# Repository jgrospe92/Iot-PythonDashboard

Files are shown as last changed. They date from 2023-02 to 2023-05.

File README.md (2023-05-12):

# Iot-PythonDashboard
Academic Project for IoT Course.

# Project Description
By utilizing sensors, actuators, motors, Single-board computers, and micro-controllers, students
design and simulate a smart home. They capture environmental information and make a decision
based on received data. They also develop access control and occupancy systems and transfer all
data to the cloud or a local server. Finally, they design and develop a web-based IoT dashboard to
control and monitor the system.

# IOT dashboard Gadgets
## LED Controll
LED_control
## LED switch Sensor
Untitled video - Made with Clipchamp

## Temperature Controll
fan_control

# Virtual Environment
## Windows
- cd to the to main directory
- Once inside Iot-PythonDashboard
- Run the command `Scripts\activate` to activate the virtual environment
- Your terminal should change into this (Iot-PythonDashboard)
- To deactivate it, run the command `deactivate`

## Arduino & MAc
- cd to the to main directory
- Once inside Iot-PythonDashboard
- Run the command `source Scripts/activate` to activate the virtual environment
- Your terminal should change into this (Iot-PythonDashboard)
- To deactivate it, run the command `deactivate`
# Important
- Make sure you name the folder Iot-PythonDashboard
- if you don't have the virtual environment installed, you can't activate the virtual environment
- run this command to install it `pip install virtualenv`

# Installing Dependencies
- Make sure you're in the python environment
- Then run the command `pip install -r requirements.txt`
- If the above command doesnt work
- You have to install each dependencies manually by running this command
- `pip install {the name of the dependency}`
- Check the requirements.txt for the names

# How to install SqLite Browser
- NOTE: You don't have to be in virtual environment to install it
- Run this command `sudo apt-get install sqlitebrowser`
- Once installed, check the raspberry icon under programming

# How to run the project
- Look for the app.py and execute it
- It should provide you a localhost address

# Email Libraries
- Red mail
  - For sending email 
  - [Documentation](https://red-mail.readthedocs.io/en/stable/tutorials/getting_started.html)
- Redbox
  - For receiving email
  - [Documentation](https://red-box.readthedocs.io/en/latest/tutorials/getting_started.html)
- :warning: IMPORTANT In order for the email function to work, you have to create email_config.py in src/Controller/
- Inside that python file add you credentials as key value pair
- example : `username = "your usename` `password = "your password"`

# MQTT Broker
- [Paho Broker](https://pypi.org/project/paho-mqtt/)
- NOTE: You must create `broker_IP.py` in src/Controller/
- Inside the python file create a variable `ipaddress = 'BROKER IP ADDRESS'`
- Replace `BROKER IP ADDRESS` with the right MQTT Broker IP address 

# wifi username and password
- In order to hide your wifi confidentials we will need to create a header file
- In the Arudino IDE click the down arrow button on the top right side of the window
- Click New Tab then name it to `arduino_secrets.h`
- then define two variables
- `#define SECRET_SSID "Your network SSID"`
- `#define SECRET_PASS "Your network password"`
- `#define SECRET_IP "Your network IP"`

# How to run the server in LAN
- set `app.run_server(host='0.0.0.0', port=1234)`
- Now we need network ip address, in ther terminal, run `ifconfig`
- you should see wlan0: ... inet x.y.z
- On the another computer, open any browser and type in the url
- the network ip address : port number
- ex. 10.0.1.2:1234
# Can't connect
- if you get an error that says, 'connection refuse'
- try using another port

# Plottly Dash Documentation
- https://dash.plotly.com/

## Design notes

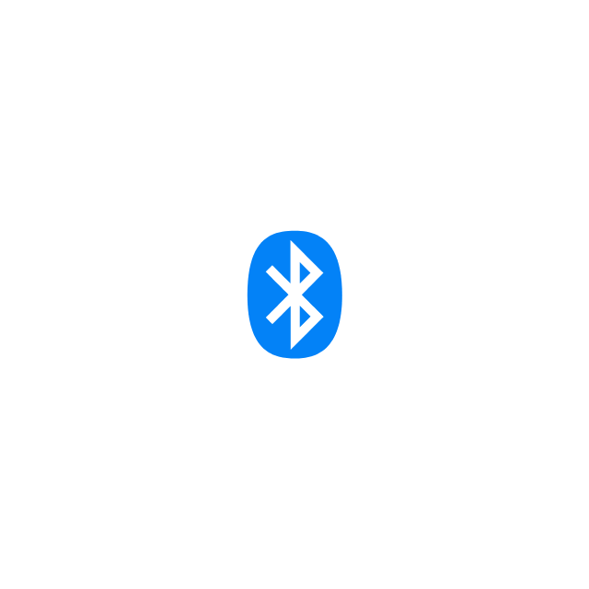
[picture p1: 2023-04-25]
assets/images/bluetooth.gif

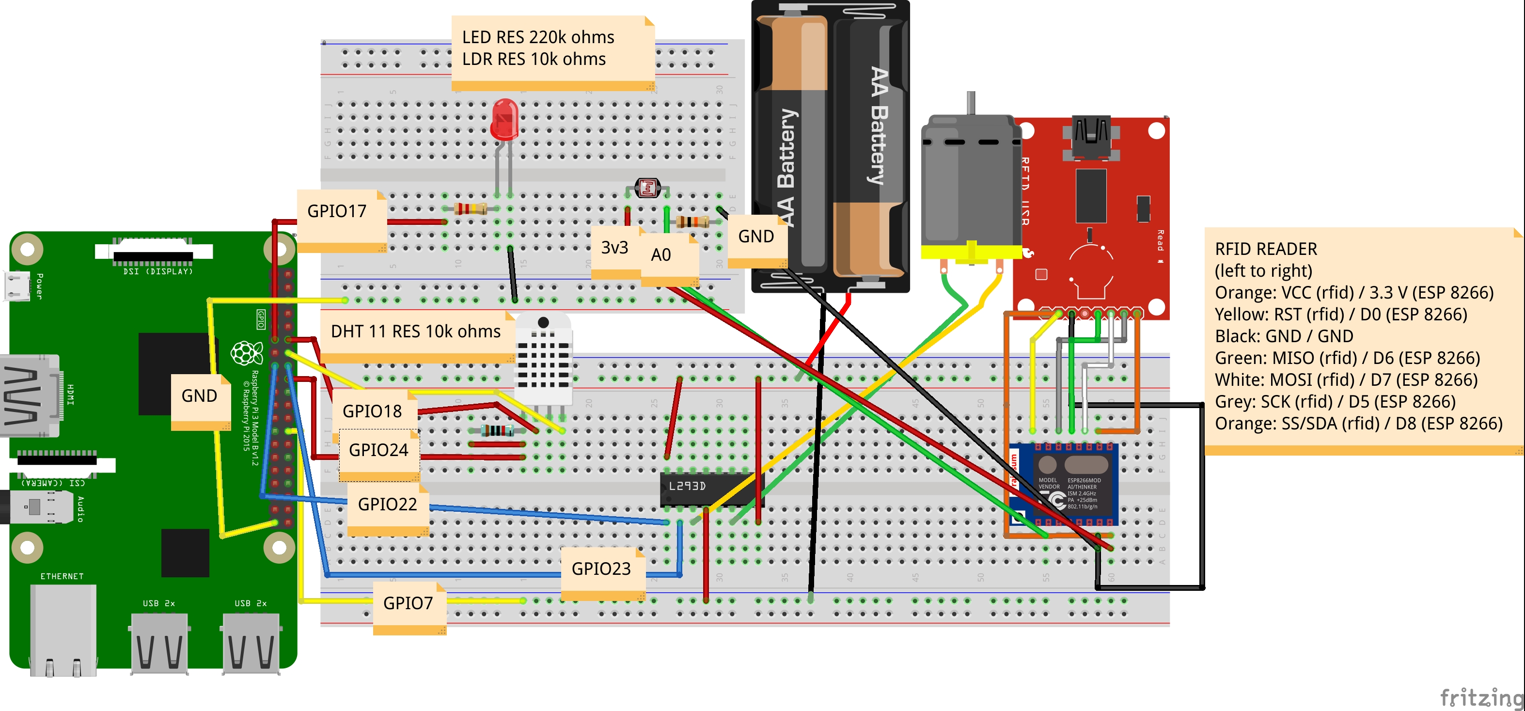
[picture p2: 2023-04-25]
Fritzing Phases/FinalFritzing_bb.jpg

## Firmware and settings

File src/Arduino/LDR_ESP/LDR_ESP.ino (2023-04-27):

#include <ESP8266WiFi.h>
#include <PubSubClient.h>
#include "arduino_secrets.h"


// RFID
#include <SPI.h>
#include <MFRC522.h>
#define SS_PIN D8
#define RST_PIN D0
MFRC522 rfid(SS_PIN, RST_PIN); // Instance of the class
MFRC522::MIFARE_Key key;
// Init array that will store new NUID
byte nuidPICC[4];
String card_id = "";


//const char* ssid = "TP-Link_2AD8";
const char* ssid = SECRET_SSID;
const char* password = SECRET_PASS;
const char* mqtt_server = SECRET_IP;
WiFiClient vanieriot;
PubSubClient client(vanieriot);
void setup_wifi() {
 delay(10);
 // We start by connecting to a WiFi network
 Serial.println();
 Serial.print("Connecting to ");
 Serial.println(ssid);
 WiFi.begin(ssid, password);
 while (WiFi.status() != WL_CONNECTED) {
 delay(500);
 Serial.print(".");
 }
 Serial.println("");
 Serial.print("WiFi connected - ESP-8266 IP address: ");
 Serial.println(WiFi.localIP());
}
void callback(String topic, byte* message, unsigned int length) {
 Serial.print("Message arrived on topic: ");
 Serial.print(topic);
 Serial.print(". Message: ");
 String messagein;

 for (int i = 0; i < length; i++) {
 Serial.print((char)message[i]);
 messagein += (char)message[i];
 }

}
void reconnect() {
 while (!client.connected()) {
 Serial.print("Attempting MQTT connection...");
 if (client.connect("vanieriot")) {
 Serial.println("connected");

 } else {
 Serial.print("failed, rc=");
 Serial.print(client.state());
 Serial.println(" try again in 3 seconds");
 // Wait 5 seconds before retrying
 delay(3000);
 }
 }
}
void setup() {

 Serial.begin(115200);
 setup_wifi();
 client.setServer(mqtt_server, 1883);
 client.setCallback(callback);
 // setup for the rfid
 SPI.begin(); // Init SPI bus
 rfid.PCD_Init(); // Init MFRC522
 Serial.println();
 Serial.print(F("Reader :"));
 rfid.PCD_DumpVersionToSerial();
 for (byte i = 0; i < 6; i++) {
  key.keyByte[i] = 0xFF;
 }
 //Note: To use the RFID RC522 module we use the SPI.h library which will allow us to
 //establish the communication between the ESP8266 card and the module; and the
 //MFRC522.h library which will allow us to dialogue with the module.
 Serial.println();
 Serial.println(F("This code scan the MIFARE Classic NUID."));
 Serial.print(F("Using the following key:"));
}
void loop() {
  delay(2000);
  if (!client.connected()) {
 reconnect();
 }
 if(!client.loop()){
  client.connect("vanieriot");
 }
 
  int sensorValue = analogRead(A0);
  char sum[5];
  itoa(sensorValue, sum, 10);
  client.publish("IoTProject/PhotoSensor",sum); 
  //client.publish("IoTlab/ESP","hi");
 
 // start of rfid
 // Reset the loop if no new card present on the sensor/reader. This saves the entire process when idle.
 // card id
if ( ! rfid.PICC_IsNewCardPresent()){
 return; 
}
 
// Verify if the NUID has been readed
if ( ! rfid.PICC_ReadCardSerial()){
 return; 
}
 
Serial.print(F("PICC type: "));
MFRC522::PICC_Type piccType = rfid.PICC_GetType(rfid.uid.sak);
Serial.println(rfid.PICC_GetTypeName(piccType));
// Check is the PICC of Classic MIFARE type
if (piccType != MFRC522::PICC_TYPE_MIFARE_MINI &&
 piccType != MFRC522::PICC_TYPE_MIFARE_1K &&
 piccType != MFRC522::PICC_TYPE_MIFARE_4K) {
 Serial.println(F("Your tag is not of type MIFARE Classic."));
 return;
}
if (rfid.uid.uidByte[0] != nuidPICC[0] ||
 rfid.uid.uidByte[1] != nuidPICC[1] ||
 rfid.uid.uidByte[2] != nuidPICC[2] ||
 rfid.uid.uidByte[3] != nuidPICC[3] ) {
 Serial.println(F("A new card has been detected."));
 // Store NUID into nuidPICC array
 for (byte i = 0; i < 4; i++) {
 nuidPICC[i] = rfid.uid.uidByte[i];
 }
 Serial.println(F("The NUID tag is:"));
 Serial.println();
 Serial.print(F("In dec: "));
 printDec(rfid.uid.uidByte, rfid.uid.size);
 card_id = String(rfid.uid.uidByte[0]) + String(rfid.uid.uidByte[1]) + String(rfid.uid.uidByte[2]) + String(rfid.uid.uidByte[3]);
 Serial.println();
 Serial.print("UID : " + card_id);
}
else {
  card_id = "false";
  // reset nuid array

   for (byte i = 0; i < 4; i++) {
 nuidPICC[i] = 0;
 }
  Serial.println(F("Card read previously."));
}


 int str_len = card_id.length() + 1;
 char char_arr[str_len];
 card_id.toCharArray(char_arr,str_len);
 client.publish("IoTlab/RFID",char_arr);


// Halt PICC
rfid.PICC_HaltA();
// Stop encryption on PCD
rfid.PCD_StopCrypto1();

 // -- end of rfid

 
 }

 /** 
 Helper routine to dump a byte array as dec values to Serial.
*/
void printDec(byte *buffer, byte bufferSize) {
for (byte i = 0; i < bufferSize; i++) {
 Serial.print(buffer[i] < 0x10 ? " 0" : " ");
 Serial.print(buffer[i], DEC);
 
}

}

void array_to_string(byte array[], unsigned int len, char buffer[])
{
  for (unsigned int i = 0; i < len ; i++)
  {
    byte nib1 = (array[i] >> 4) & 0x0F;
    byte nib2 = (array[i] >> 0) & 0x0F;
    buffer[i * 2 + 0] = nib1 < 0xA ? '0' + nib1 : 'A' + nib1 - 0xA;
    buffer[i * 2 + 1] = nib2 < 0xA ? '0' + nib2 : 'A' + nib2 - 0xA; 
  }
  buffer[len * 2] = '\0';
}

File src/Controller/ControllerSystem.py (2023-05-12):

# This class handles all functionalities when connecting to the Raspberry

from redmail import EmailSender
from redbox import EmailBox
from . import email_config
import time
from time import sleep
from datetime import datetime
from src.Helper import SqLiteDbHelper as dbHelper
# Import Rpi and sleep libraries
# Uncomment this if your working on your GPIO
import RPi.GPIO as GPIO

# Set a global flag
# Photoresistor Value
sensorValue = 1000;
BT_counter = 0

# RDIS
rfid_userID = ""
logged_in = False

# Thresholds
light_sensor_threshold = 0
temperature_threshold = 0

isActive = 0  # this tells the program if the light is on or off
LED = 16 # Enable pin GPIO23
LED_ON = False # status of the LED
LOW_LIGHT = False
# EMAIL_STATUS is a boolean flag that indicates if the email is sent
EMAIL_STATUS = False
# email status for the light sensor
EMAIL_SENSOR_STATUS = False
# email status for user login
EMAIL_LOGIN_STATUS = False
# FAN_ON is a boolean flag that indicates if the fan is on
FAN_ON = False
# global DHT
dht = None;
# MOTO PINS
Motor1 = 15  # Enable Pin GPIO22
Motor2 = 13  # Input Pin GPIO27
Motor3 = 29  # Input Pin GPIO05



"""
@PARAMS
@RETURN
DESC: DHT class
"""
class DHT(object):
    DHTLIB_OK = 0
    DHTLIB_ERROR_CHECKSUM = -1
    DHTLIB_ERROR_TIMEOUT = -2
    DHTLIB_INVALID_VALUE = -999

    DHTLIB_DHT11_WAKEUP = 0.020  # 0.018		#18ms
    DHTLIB_TIMEOUT = 0.0001  # 100us

    humidity = 0
    temperature = 0

    def __init__(self, pin):
        self.pin = pin
        self.bits = [0, 0, 0, 0, 0]
        # GPIO.setmode(GPIO.BOARD)
        #GPIO.setmode(GPIO.BCM)

    # Read DHT sensor, store the original data in bits[]
    def readSensor(self, pin, wakeupDelay):
        mask = 0x80
        idx = 0
        self.bits = [0, 0, 0, 0, 0]
        # Clear sda
        GPIO.setup(pin, GPIO.OUT)
        GPIO.output(pin, GPIO.HIGH)
        time.sleep(0.5)
        # start signal
        GPIO.output(pin, GPIO.LOW)
        time.sleep(wakeupDelay)
        GPIO.output(pin, GPIO.HIGH)
        # time.sleep(0.000001)
        GPIO.setup(pin, GPIO.IN)

        loopCnt = self.DHTLIB_TIMEOUT
        # Waiting echo
        t = time.time()
        while True:
            if (GPIO.input(pin) == GPIO.LOW):
                break
            if ((time.time() - t) > loopCnt):
                return self.DHTLIB_ERROR_TIMEOUT
        # Waiting echo low level end
        t = time.time()
        while (GPIO.input(pin) == GPIO.LOW):
            if ((time.time() - t) > loopCnt):
                # print ("Echo LOW")
                return self.DHTLIB_ERROR_TIMEOUT
        # Waiting echo high level end
        t = time.time()
        while (GPIO.input(pin) == GPIO.HIGH):
            if ((time.time() - t) > loopCnt):
                # print ("Echo HIGH")
                return self.DHTLIB_ERROR_TIMEOUT
        for i in range(0, 40, 1):
            t = time.time()
            while (GPIO.input(pin) == GPIO.LOW):
                if ((time.time() - t) > loopCnt):
                    # print ("Data Low %d"%(i))
                    return self.DHTLIB_ERROR_TIMEOUT
            t = time.time()
            while (GPIO.input(pin) == GPIO.HIGH):
                if ((time.time() - t) > loopCnt):
                    # print ("Data HIGH %d"%(i))
                    return self.DHTLIB_ERROR_TIMEOUT
            if ((time.time() - t) > 0.00005):
                self.bits[idx] |= mask
            # print("t : %f"%(time.time()-t))
            mask >>= 1
            if (mask == 0):
                mask = 0x80
                idx += 1
        # print (self.bits)
        GPIO.setup(pin, GPIO.OUT)
        GPIO.output(pin, GPIO.HIGH)
        return self.DHTLIB_OK

    # Read DHT sensor, analyze the data of temperature and humidity
    def readDHT11Once(self):
        rv = self.readSensor(self.pin, self.DHTLIB_DHT11_WAKEUP)
        if (rv is not self.DHTLIB_OK):
            self.humidity = self.DHTLIB_INVALID_VALUE
            self.temperature = self.DHTLIB_INVALID_VALUE
            return rv
        self.humidity = self.bits[0]
        self.temperature = self.bits[2] + self.bits[3] * 0.1
        sumChk = ((self.bits[0] + self.bits[1] + self.bits[2] + self.bits[3]) & 0xFF)
        if (self.bits[4] is not sumChk):
            return self.DHTLIB_ERROR_CHECKSUM
        return self.DHTLIB_OK

    def readDHT11(self):
        result = self.DHTLIB_INVALID_VALUE
        for i in range(0, 15):
            result = self.readDHT11Once()
            if result == self.DHTLIB_OK:
                return self.DHTLIB_OK
            time.sleep(0.1)
        return result

"""
@PARAMS
@RETURN
DESC: Important! this set ups all the required pins, setmode and setup
    needed for the circuit to work
"""
def set_up():
    global LED, dht
    GPIO.setwarnings(False)
    GPIO.setmode(GPIO.BOARD)
    # INITIALIZE BOARD PINS

    # SET UP
    GPIO.setup(LED, GPIO.OUT, initial=GPIO.LOW)

    # DHT SetUp
    dht = DHT(11)

    # motor setup
    GPIO.setup(Motor1, GPIO.OUT)
    GPIO.setup(Motor2, GPIO.OUT)
    GPIO.setup(Motor3, GPIO.OUT)

"""
@PARAMS
@RETURN int 
DESC: controlls when to turn on the light
"""
def light_controller() -> int:
    global isActive
    if isActive == 1:
        # Turn the light off
        GPIO.output(LED, 0)
        isActive = 0
        return 0
    else:
        # Turn the light on
        isActive = 1
        GPIO.output(LED, 1)
        return 1

"""
@PARAMS
@RETURN
DESC: turns the LED on based on the light sensor value
"""
def light_switch_sensor() -> bool:
    global LOW_LIGHT, light_sensor_threshold
    print(str(sensorValue))
    if sensorValue < light_sensor_threshold:
        GPIO.output(LED,1)
        LOW_LIGHT = True
        return  True
    else:
        LOW_LIGHT = False
        GPIO.output(LED,0)
        return False

"""
@PARAMS temp : int, email_to : str
@RETURN
DESC: emmail the temperature to the reciever 
"""
def send_email(temp: int, email_to: str):
    global EMAIL_STATUS
    # If the EMAIL_STATUS is False, then we can send the email
    if not EMAIL_STATUS:
        # create an instance of email
        email = EmailSender(
            host="smtp.gmail.com",
            port=587,
            username=email_config.username,
            password=email_config.password)
        # send the email with the temperature value
        email.send(
            subject="Alert",  # Email Subject
            sender="jgrospetest@gmail.com",
            receivers=[email_to],
            text="The current temperature is {{ temp }},\n"
                 "would you like to turn on the fan? \n"
                 "**reply with (YES/NO) or (STOP) to turn the fan off ",
            body_params=
            {
                "temp": temp
            }
        )
        print("Message Sent!")
    # Once the email is sent, Set EMAIL_STATUS to True, so it wont keep sending it
    EMAIL_STATUS = True
    print("EMAIL STATUS : ", end="")
    print(EMAIL_STATUS)
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

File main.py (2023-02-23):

from dash import Dash, html, Input, Output
import time
# from dash_bootstrap_components.themes import BOOTSTRAP
import dash_bootstrap_components as dbc
from dash.exceptions import PreventUpdate
from src.components.layout import create_layout
import src.Controller.ControllerSystem as cs


# Import RPi and time libraris
# Temporary disabled these libraries / uncomment it if you are using your Raspberry pi
# import RPi.GPIO as GPIO
# from time import sleep

def main() -> None:
    app = Dash(external_stylesheets=[dbc.themes.SLATE])
    app.title = "IOT DashBoard"
    app.layout = create_layout(app)

    # NOTE: Uncomment this if you are using your raspberry pi
    #cs.set_up()

    # Callbacks for the button switch
    @app.callback(
        Output(component_id='btn-activate', component_property='children'),
        Input(component_id='btn-activate', component_property='n_clicks'),
    )
    def update_button(n_clicks):
        global isActive
        if n_clicks is None:
            raise PreventUpdate
        else:
            # Tenary operator return OFF if condiion is == 0 else ON
            return "OFF" if cs.light_controller() == 0 else "ON"

    # Callback for the lightbulb
    @app.callback(
        Output(component_id='lightbulb', component_property="children"),
        Input(component_id='btn-activate', component_property='n_clicks')
    )
    def update_lightbulb(n_clicks):
        global isActive
        if n_clicks is None:
            raise PreventUpdate
        else:
            # Tenary operator return OFF if condiion is == 0 else ON
            return "<b>background-color: #000<b>" if cs.isActive == 0 else "background-color: #FFDB12"

    app.run()


if __name__ == "__main__":
    main()

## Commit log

2023-02-22 add python virtual env
    [pyvenv.cfg]
2023-02-23 major update
    refactor codes
    add dash_daq
    change switch button to power button
    create new classes
2023-02-23 fix connition with the gpio
    [ControllerSystem.py]
2023-02-25 fix bug, add external styling,
    fix bug where clicking the button rapidly causes the lightbulb to be out of sync
    fix bug where importing color doesnt work
    add external bootstrap styling
    [ControllerSystem.py, app.py]
2023-03-02 fix the bug with the
    fix the bug where the LED on the breadboard is not activating
    [ControllerSystem.py]
2023-03-19 add phase 2 gadgets
    add gauge & fan
2023-03-19 add css rotate
    rotates the fan
2023-03-19 add temp_controller script
    this will read the temperature from the DHT11
2023-03-19 Update README.md
    change the gif for the fan control
2023-03-21 add thermometer callabacks
    add callback to check if temperature value is > 24
    change thermometer color
2023-03-21 Test dcc.Store
    testing an algorithm to process receiving email and activate the fan
2023-03-21 Update ControllerSystem.py
    Fix email_config
    [ControllerSystem.py]
2023-03-23 phase 2 patch
    - add motor method to control the fun
    - remove temp_controller.py
    - remove 'c' unit in the thermometer
2023-03-29 Phases 2 visual plan completed
    [phase2.fzz]
2023-03-29 Phase 1 fritzing
    [Phase1.fzz]
2023-03-29 Db added
    with some sample data (no pic included)
2023-03-29 phase 3 fritzing completed
    [phase3.fzz]
2023-03-30 add graduatedBar
    remove power button
    add graduated bar to represent light intensity
2023-03-31 fix dht not found
    [ControllerSystem.py]
2023-03-31 fix motor pin error
    make the motor pin # global
    [ControllerSystem.py]
2023-03-31 fix dht and motor
    remove GPIO.cleanup()
    [ControllerSystem.py]
2023-03-31 add paho broker script
    add instruction on how to include the mqtt broker
    [Paho_Broker.py]
2023-04-01 node-red Attempt from photoresistor data
    doesn't give me an error to track where to fix
    I keep getting error in the mqtt broker error to connect when trying to start node-red can still open node red but not the mqtt server broker
2023-04-01 add arduino code
2023-04-01 Update Paho_Broker.py
    add topic to the broker
    [Paho_Broker.py]
2023-04-02 add light sensor functionality
    able to read light sensor from the broker and change the light value
    [ControllerSystem.py, Paho_Broker.py, app.py]
2023-04-02 finish phase 3
    - read the data from the broker, if data is below 400 switch the light on and send an email notification
    -
    [ControllerSystem.py]
2023-04-02 Update README.md
    add gif for LED sensor
2023-04-02 Updated Photoresistor
    it gives me the voltage updated constant only on serial monitor (idk why it doesn't display on node-red it's connected, it should be outputting the values but nothing display on the debug.)
2023-04-02 updated phase 3 fritzing
    corrected the phase 3 fritzing
    [phase3.fzz]
2023-04-13 RFID idea
    [Phase1.fzz, phase2.fzz, phase3.fzz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]
2023-04-14 Revert "RFID idea"
    This reverts commit 849cb193c0af1b45fe96964c07384589973419a6.
    [Phase1.fzz, phase2.fzz, phase3.fzz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]
2023-04-16 mod db
    - add sample data to the database
2023-04-19 add rfid script to the broker script
    [ESP-RFID.ino, LDR_ESP.ino]
2023-04-20 add script to read data from the db
    - add python script to interact with the db
    - change id int to id text
    - replace all values to read from the db
    - add barcode column to the db
    [ControllerSystem.py, app.py]
2023-04-22 add functions to get user data by id
    - ability to update the dashboard base on the current user data
2023-04-23 testing rfid and broker
    [LDR_ESP.ino]
2023-04-23 Revert "testing rfid and broker"
    This reverts commit bd58108d091e16f25d72444dffd064718e018088.
    [LDR_ESP.ino]
2023-04-25 Phase 4 fritzing
    all phase together included
    [FinalFritzing.fzz]
